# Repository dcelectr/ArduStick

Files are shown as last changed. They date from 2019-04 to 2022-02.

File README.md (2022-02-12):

# ArduStick
Arduino compatible board (ATmega 328P) for breadboards or small projects where space is limited.
The J3 through J5 are intended to be populated by a single row 23 pin female socket, but it can be substituted (since the footprint is the same for 0.1" pin spacing) with 90 degree (horizontal) male header if you want to plug the ArduStick directly on a breadboard.
This design has been built and tested. It works! 

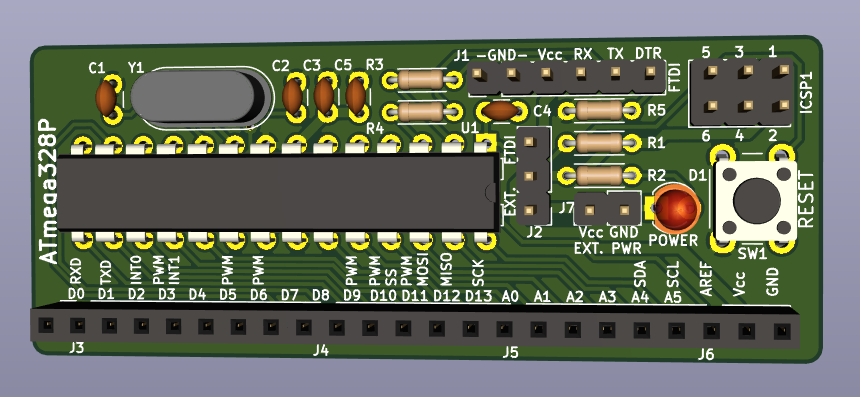
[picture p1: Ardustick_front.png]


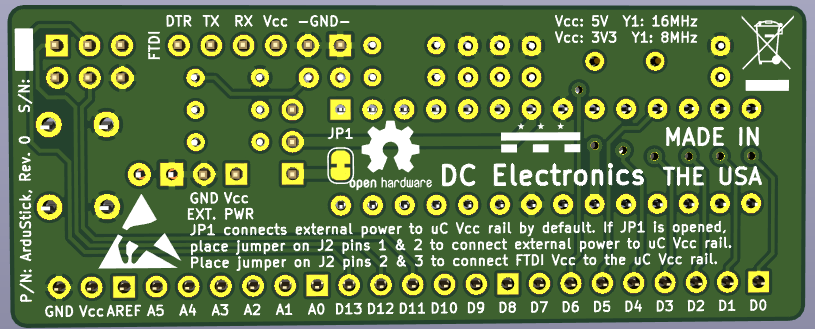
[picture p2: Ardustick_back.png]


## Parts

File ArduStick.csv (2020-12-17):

Reference | Quantity | Value | Part Number | Footprint
C1 C2 | 2 | 22pF | K220J15C0GF5TL2 | Capacitor_THT:C_Disc_D3.0mm_W1.6mm_P2.50mm
C3 C4 C5 | 3 | 100nF | C320C104K5R5TA7317 | Capacitor_THT:C_Disc_D3.0mm_W1.6mm_P2.50mm
D1 | 1 | LED | 3mm LED | LED_THT:LED_D3.0mm
ICSP1 | 1 | Conn_02x03_Odd_Even | 2x3 male header | Connector_PinHeader_2.54mm:PinHeader_2x03_P2.54mm_Vertical
J1 | 1 | Conn_01x06_Male | 1x6 male header | Connector_PinHeader_2.54mm:PinHeader_1x06_P2.54mm_Vertical
J2 | 1 | Conn_01x03_Male | 1x3 male header | Connector_PinHeader_2.54mm:PinHeader_1x03_P2.54mm_Vertical
J3 | 1 | Conn_01x08_Female | PRPC040SBAN-M71RC (cur to lenth) or PPTC231LFBN-RC | Connector_PinSocket_2.54mm:PinSocket_1x08_P2.54mm_Vertical
J4 J5 | 2 | Conn_01x06_Female | See J3 | Connector_PinSocket_2.54mm:PinSocket_1x06_P2.54mm_Vertical
J6 | 1 | Conn_01x03_Female | See J3 | Connector_PinSocket_2.54mm:PinSocket_1x03_P2.54mm_Vertical
J7 | 1 | Conn_01x02_Male | 1x5 male header | Connector_PinHeader_2.54mm:PinHeader_1x02_P2.54mm_Vertical
JP1 | 1 | SolderJumper_2_Bridged | N/A | Jumper:SolderJumper-2_P1.3mm_Bridged_RoundedPad1.0x1.5mm
R1 | 1 | 10K | 1/8W 10 kOhms | Resistor_THT:R_Axial_DIN0204_L3.6mm_D1.6mm_P5.08mm_Horizontal
R2 R3 R4 R5 | 4 | 1K | 1/8W 1 kOhms | Resistor_THT:R_Axial_DIN0204_L3.6mm_D1.6mm_P5.08mm_Horizontal
SW1 | 1 | RESET_SWITCH | 1825910-6 | Button_Switch_THT:SW_PUSH_6mm
U1 | 1 | ATmega328P-PU | ATmega328P-PU | Package_DIP:DIP-28_W7.62mm
Y1 | 1 | Crystal 16MHz | 9B-16.000MBBK-B | Crystal:Crystal_HC49-4H_Vertical

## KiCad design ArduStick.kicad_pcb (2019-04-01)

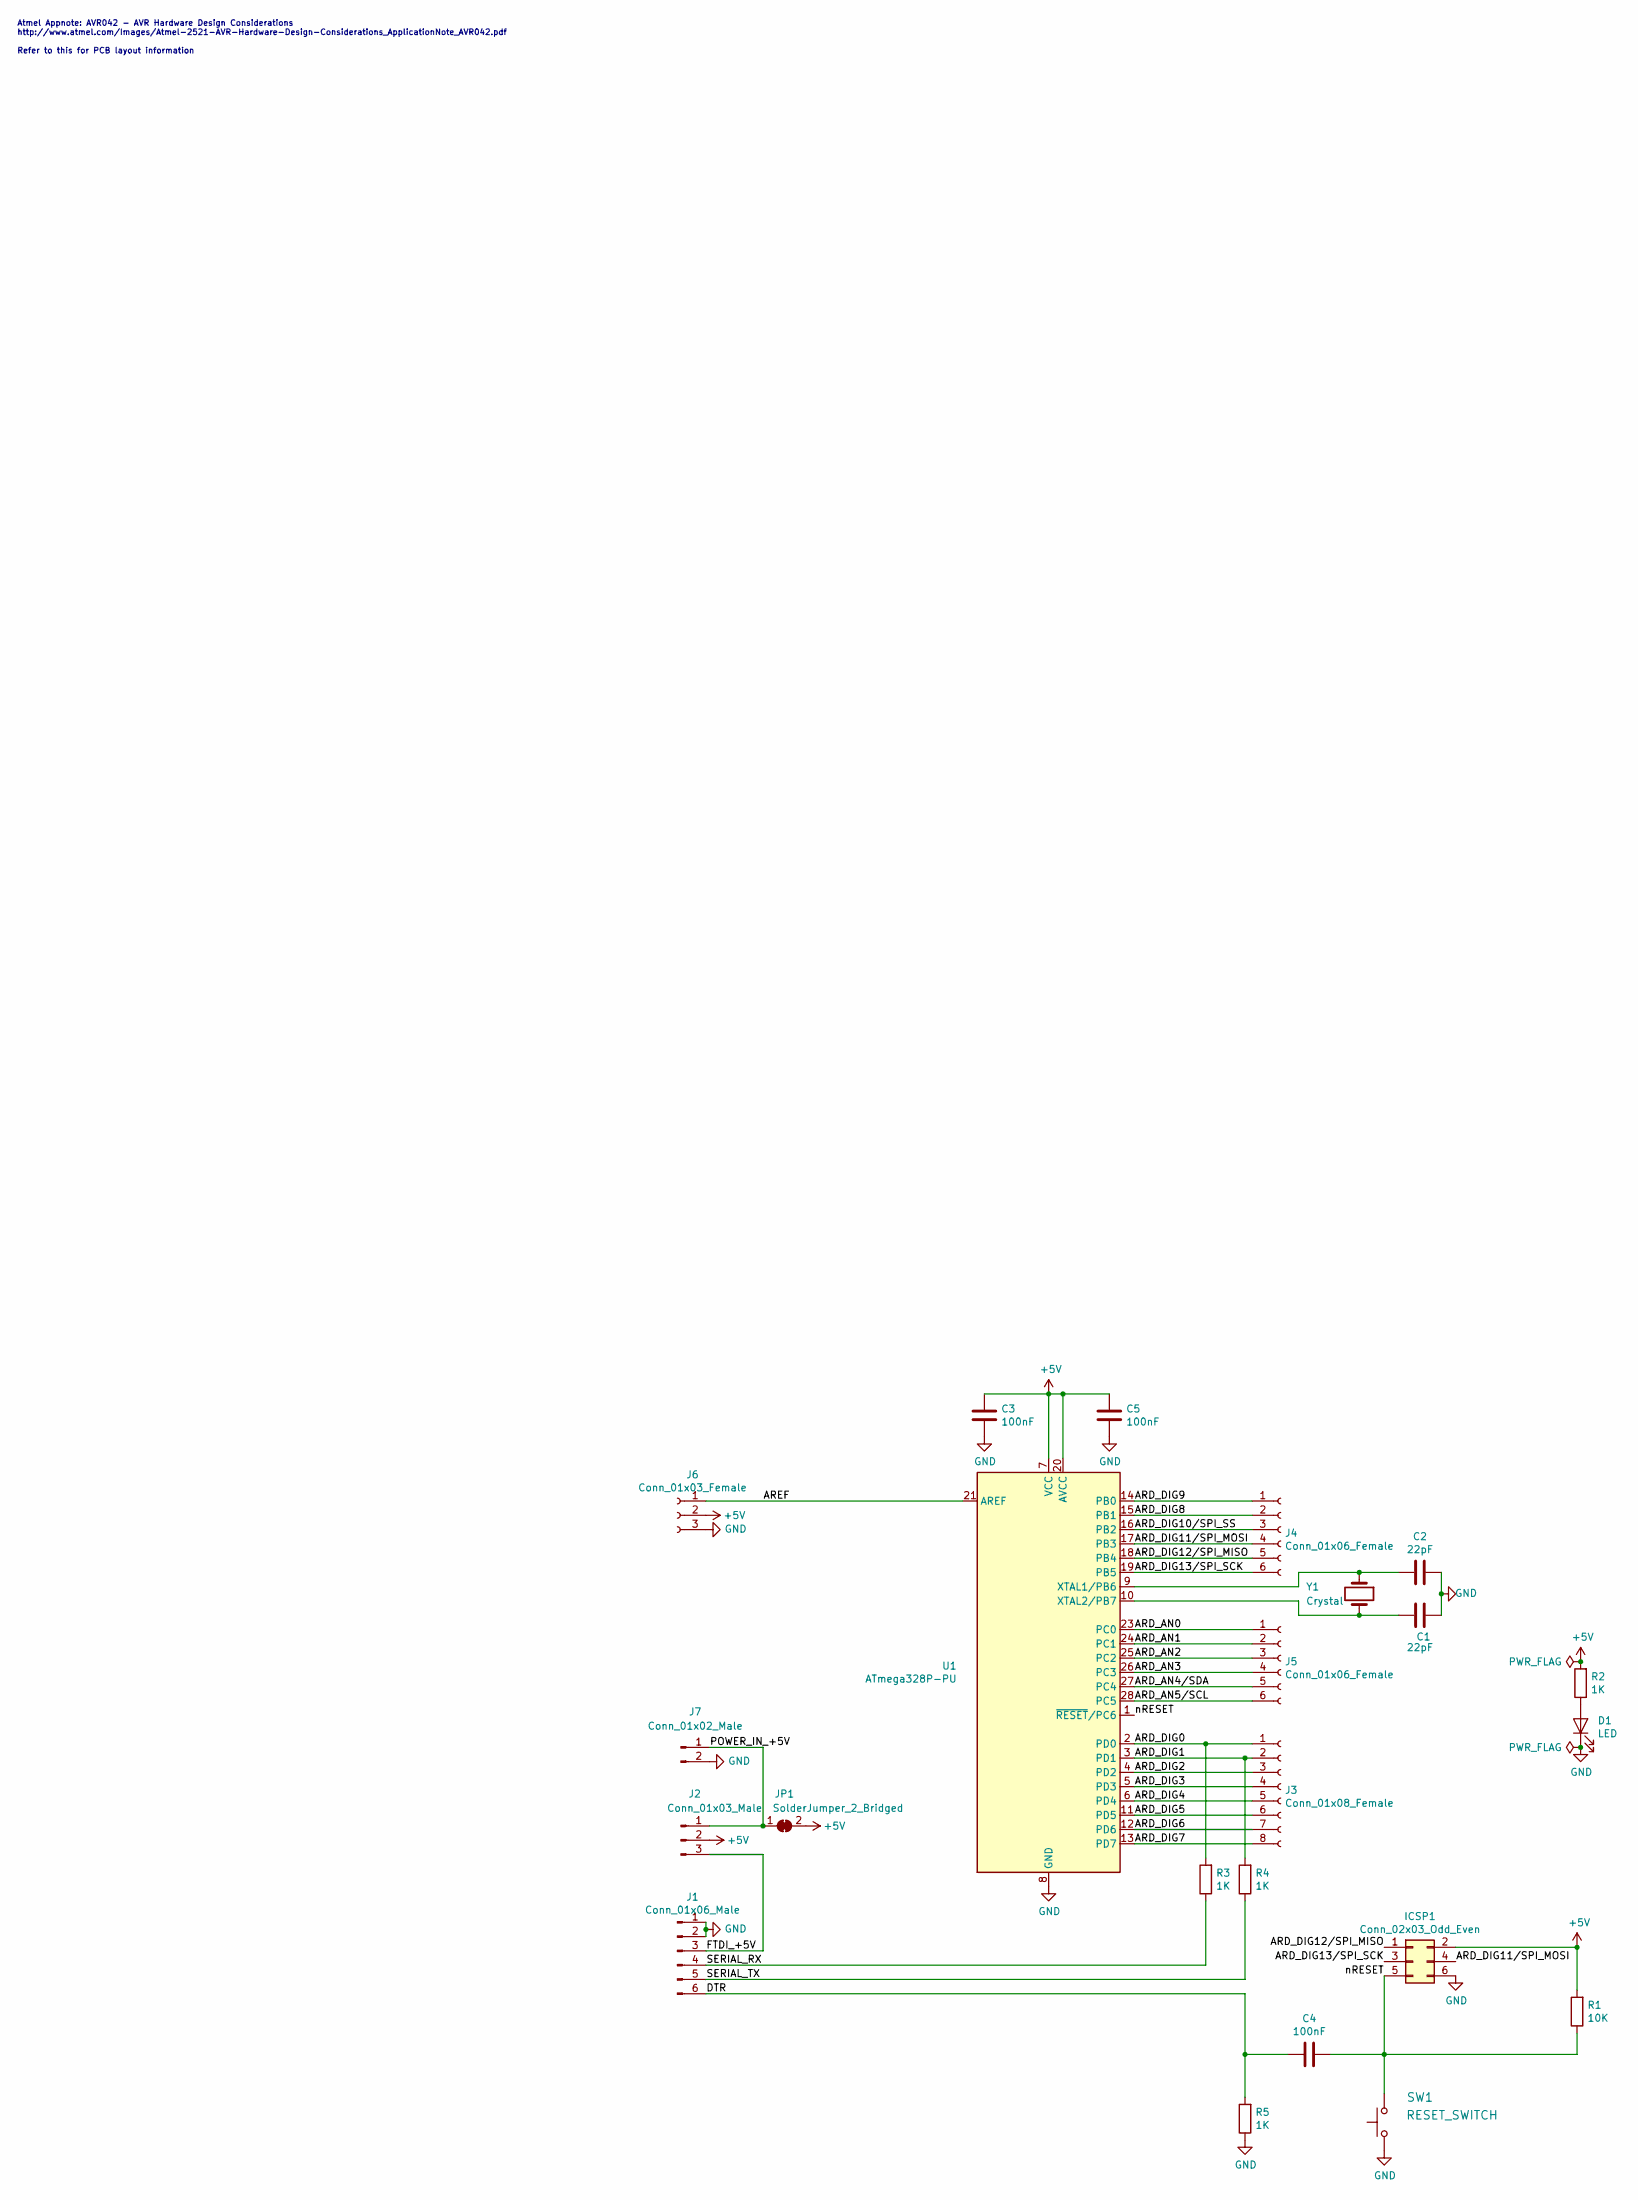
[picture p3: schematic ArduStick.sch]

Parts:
C1, C2: 22pF; C_Disc_D3.0mm_W1.6mm_P2.50mm
C3, C4, C5: 100nF; C_Disc_D3.0mm_W1.6mm_P2.50mm
D1: LED; LED_D3.0mm
ICSP1: Conn_02x03_Odd_Even; PinHeader_2x03_P2.54mm_Vertical
J1: Conn_01x06_Male; PinHeader_1x06_P2.54mm_Vertical
J2: Conn_01x03_Male; PinHeader_1x03_P2.54mm_Vertical
J3: Conn_01x08_Female; PinSocket_1x08_P2.54mm_Vertical
J4, J5: Conn_01x06_Female; PinSocket_1x06_P2.54mm_Vertical
J6: Conn_01x03_Female; PinSocket_1x03_P2.54mm_Vertical
J7: Conn_01x02_Male; PinHeader_1x02_P2.54mm_Vertical
JP1: SolderJumper_2_Bridged; SolderJumper-2_P1.3mm_Bridged_RoundedPad1.0x1.5mm
R1: 10K; R_Axial_DIN0204_L3.6mm_D1.6mm_P5.08mm_Horizontal
R2, R3, R4, R5: 1K; R_Axial_DIN0204_L3.6mm_D1.6mm_P5.08mm_Horizontal
SW1: RESET_SWITCH; SW_PUSH_6mm
U1: ATmega328P-PU; DIP-28_W7.62mm
Y1: Crystal; Crystal_HC49-4H_Vertical

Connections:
+5V: C3.1, C5.1, ICSP1.2, J2.2, J6.2, JP1.2 (B), R1.2, R2.2, U1.7 (VCC), U1.20 (AVCC)
/ARD_AN0: J5.1, U1.23 (PC0)
/ARD_AN1: J5.2, U1.24 (PC1)
/ARD_AN2: J5.3, U1.25 (PC2)
/ARD_AN3: J5.4, U1.26 (PC3)
/ARD_AN4/SDA: J5.5, U1.27 (PC4)
/ARD_AN5/SCL: J5.6, U1.28 (PC5)
/ARD_DIG0: J3.1, R3.2, U1.2 (PD0)
/ARD_DIG1: J3.2, R4.2, U1.3 (PD1)
/ARD_DIG2: J3.3, U1.4 (PD2)
/ARD_DIG3: J3.4, U1.5 (PD3)
/ARD_DIG4: J3.5, U1.6 (PD4)
/ARD_DIG5: J3.6, U1.11 (PD5)
/ARD_DIG6: J3.7, U1.12 (PD6)
/ARD_DIG7: J3.8, U1.13 (PD7)
/ARD_DIG8: J4.2, U1.15 (PB1)
/ARD_DIG9: J4.1, U1.14 (PB0)
/ARD_DIG10/SPI_SS: J4.3, U1.16 (PB2)
/ARD_DIG11/SPI_MOSI: ICSP1.4, J4.4, U1.17 (PB3)
/ARD_DIG12/SPI_MISO: ICSP1.1, J4.5, U1.18 (PB4)
/ARD_DIG13/SPI_SCK: ICSP1.3, J4.6, U1.19 (PB5)
/AREF: J6.1, U1.21 (AREF)
/DTR: C4.2, J1.6, R5.2
/FTDI_+5V: J1.3, J2.3
/POWER_IN_+5V: J2.1, J7.1, JP1.1 (A)
/SERIAL_RX: J1.4, R3.1
/SERIAL_TX: J1.5, R4.1
/nRESET: C4.1, ICSP1.5, R1.1, SW1.2, U1.1 (~RESET~/PC6)
GND: C1.1, C2.1, C3.2, C5.2, D1.1 (K), ICSP1.6, J1.1, J1.2, J6.3, J7.2, R5.1, SW1.1, U1.8 (GND), U1.22 (GND)
unnamed: C1.2, U1.10 (XTAL2/PB7), Y1.2
unnamed: C2.2, U1.9 (XTAL1/PB6), Y1.1
unnamed: D1.2 (A), R2.1

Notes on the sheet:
Atmel Appnote: AVR042 - AVR Hardware Design Considerations http://www.atmel.com/Images/Atmel-2521-AVR-Hardware-Design-Considerations_ApplicationNote_AVR042.pdf Refer to this for PCB layout information

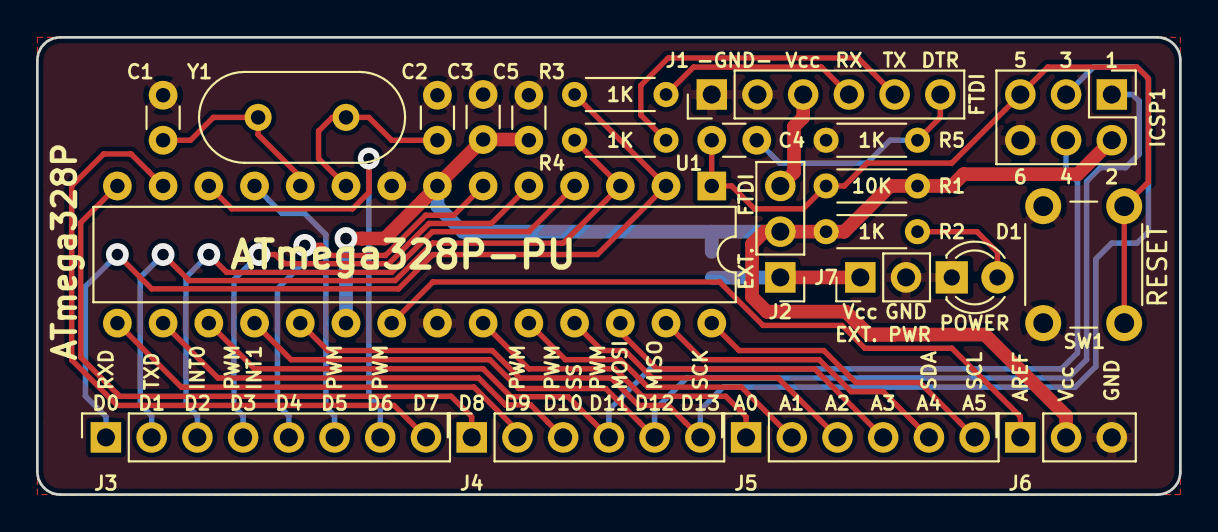
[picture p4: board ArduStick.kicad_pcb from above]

Board: 2 copper layers, 63.5 x 25.4 mm, 23 parts (1 on the bottom side), 32 nets.

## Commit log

2019-07-09 3D renderings
    The J3 through J5 female sockets can be substituted (since the footprint is the same for 0.1" pin spacing) by 90 degree (horizontal) male headers if you want to plug the Ardustick directly on a bread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
2020-12-17 Added Bill of Materials CSV file
    [ArduStick.csv]
